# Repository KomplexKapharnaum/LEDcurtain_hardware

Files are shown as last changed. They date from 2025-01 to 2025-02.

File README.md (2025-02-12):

# Teensy KxKm Artnet Node Hardware
**Version: V1.5.0**
# Clément SAILLANT pour KomplexKapharnaüm

Ce projet est la partie hardware d'un nœud Artnet basé sur Teensy 4.1 pour contrôler jusqu'a 50 bandes LED. La Teensy 4.1 est un microcontrôleur puissant capable de piloter un grand nombre de LEDs. Ce projet utilise la bibliothèque FastLED et objectFLED pour contrôler les LEDs et la bibliothèque Artnet pour recevoir les données Artnet.

ce repo contient le Schéma et PCB pour la gestion jusqu'à 40 ruban led en artnet (ou autres) avec une teensy 4.1
avec gestion d'alimentation pour économiser l'énergie quand les ruban de led n'affiche rien.

code disponible ici :
https://github.com/KomplexKapharnaum/LEDcurtain/tree/main

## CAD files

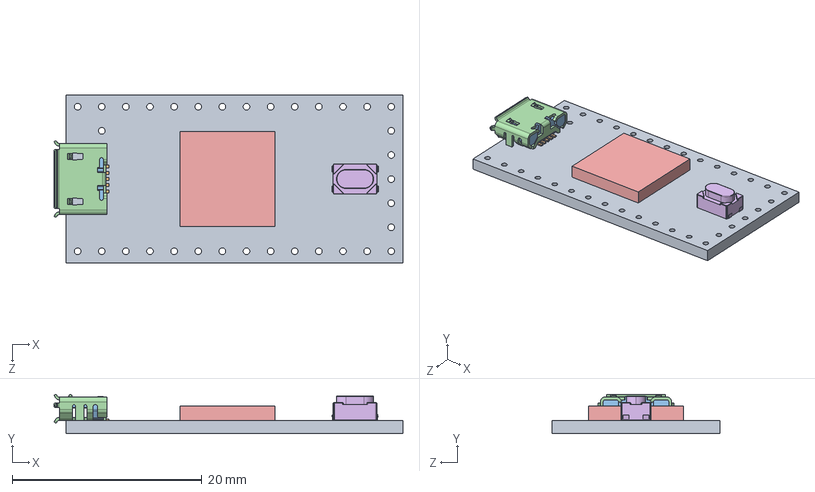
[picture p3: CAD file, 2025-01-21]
Librairie/teensy.pretty-master/Teensy_4.0_Assembly.STEP
36.8 x 4.12 x 17.7 mm
Teensy_4.0_PCB
Micro USB-B Female 5Pin SMD
NXP iMXRT1062
SKRPACE010 v4

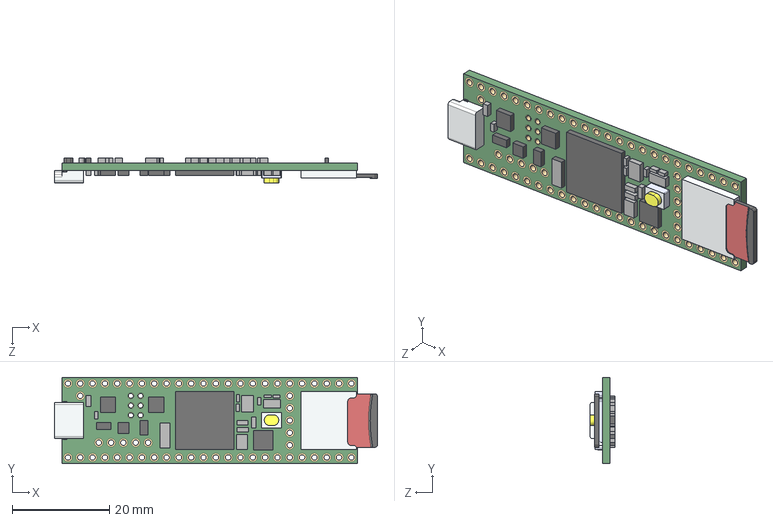
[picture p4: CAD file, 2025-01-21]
casing/Teensy_4.1_Assembly_simplified.STEP
66.6 x 17.8 x 5.06 mm

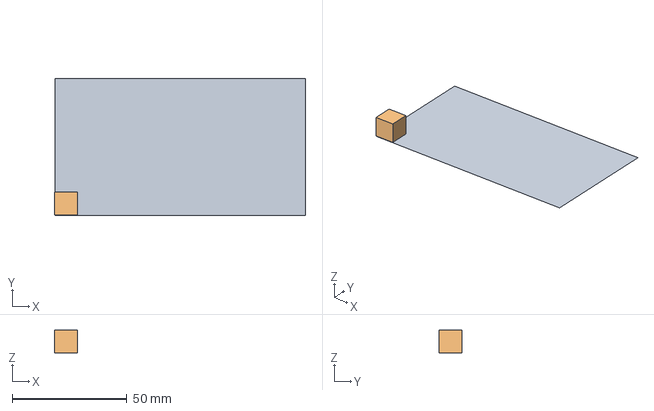
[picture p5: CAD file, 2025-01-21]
casing/LED Board.FCStd
109.6 x 59.8 x 10.0 mm
Rectangle

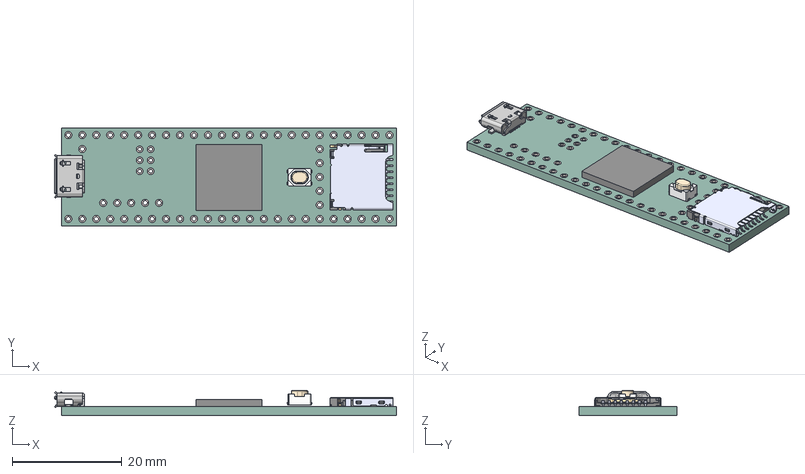
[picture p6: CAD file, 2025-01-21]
casing/teensy-4-1-development-board-1/Teensy 4.1 (Without Headers).step
62.2 x 17.8 x 4.62 mm
114-00841-68--3DModel-STEP-56544
MIMXRT1052CVJ5B
MicroUSB Molex 473460001
PTS810 SJK 250 SMTR LFS

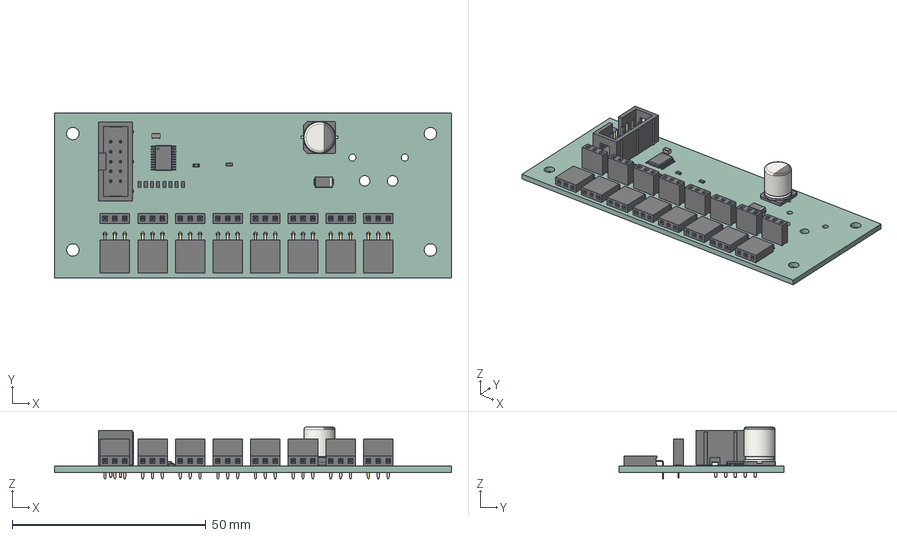
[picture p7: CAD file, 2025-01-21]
LED Board/LED Board.step
102.4 x 42.4 x 13.3 mm
R_0603_1608Metric x 10
PinSocket_1x03_P254mm_Horizontal x 8
PinSocket_1x03_P254mm_Vertical x 8
C_0805_2012Metric
D_SMA
CP_Elec_8x10
IDC_Header_2x05_P254mm_Vertical
TSSOP_20_44x65mm_P065mm
LED Board_PCB

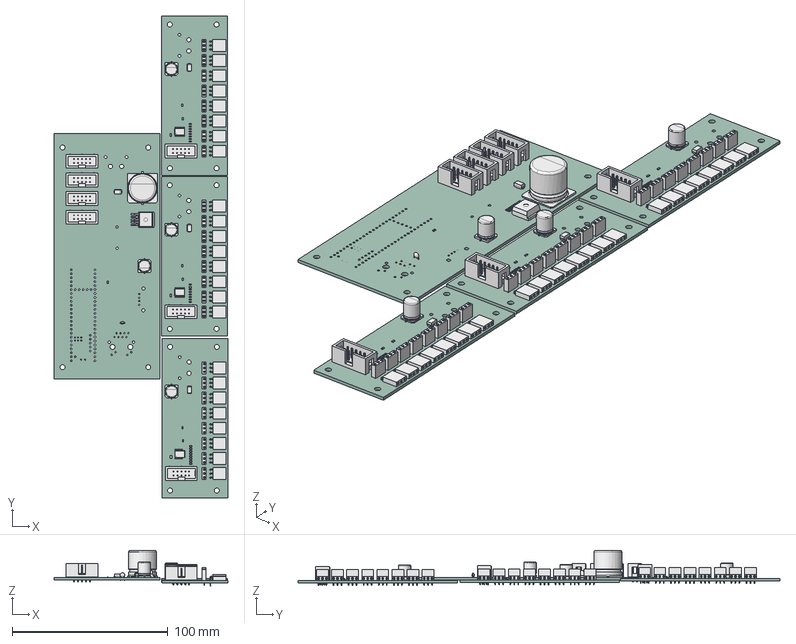
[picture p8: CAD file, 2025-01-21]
casing/Casing all board.FCStd
111.7 x 309.3 x 22.7 mm
CQ assembly
IDC_Header_2x05_P254mm_Vertical
IDC_Header_2x05_P254mm_Vertical001
C_Disc_D30mm_W16mm_P250mm
IDC_Header_2x05_P254mm_Vertical002
CP_Elec_8x10
CP_Elec_18x175
R_0603_1608Metric
D_SMA
IDC_Header_2x05_P254mm_Vertical003
Teensy Board_PCB
R_0603_1608Metric002
PinSocket_1x03_P254mm_Horizontal
PinSocket_1x03_P254mm_Vertical
PinSocket_1x03_P254mm_Vertical001
PinSocket_1x03_P254mm_Horizontal001
PinSocket_1x03_P254mm_Vertical002
PinSocket_1x03_P254mm_Horizontal002
PinSocket_1x03_P254mm_Vertical003
R_0603_1608Metric004
PinSocket_1x03_P254mm_Horizontal003
R_0603_1608Metric006
PinSocket_1x03_P254mm_Vertical004
C_0805_2012Metric
PinSocket_1x03_P254mm_Horizontal004
D_SMA002
R_0603_1608Metric008
R_0603_1608Metric010
R_0603_1608Metric012
R_0603_1608Metric014
PinSocket_1x03_P254mm_Horizontal005
CP_Elec_8x012
PinSocket_1x03_P254mm_Vertical005
PinSocket_1x03_P254mm_Vertical006
R_0603_1608Metric016
PinSocket_1x03_P254mm_Vertical007
PinSocket_1x03_P254mm_Horizontal006
R_0603_1608Metric018
IDC_Header_2x05_P254mm_Vertical004
R_0603_1608Metric020
TSSOP_20_44x65mm_P065mm
PinSocket_1x03_P254mm_Horizontal007
_autosave-LED Board_PCB
R_0603_1608Metric022
PinSocket_1x03_P254mm_Horizontal008
PinSocket_1x03_P254mm_Vertical008
PinSocket_1x03_P254mm_Vertical009
PinSocket_1x03_P254mm_Horizontal009
PinSocket_1x03_P254mm_Vertical010
PinSocket_1x03_P254mm_Horizontal010
PinSocket_1x03_P254mm_Vertical011
R_0603_1608Metric024
PinSocket_1x03_P254mm_Horizontal011
R_0603_1608Metric026
PinSocket_1x03_P254mm_Vertical012
C_0805_2012Metric002
PinSocket_1x03_P254mm_Horizontal012
D_SMA004
R_0603_1608Metric028
R_0603_1608Metric030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

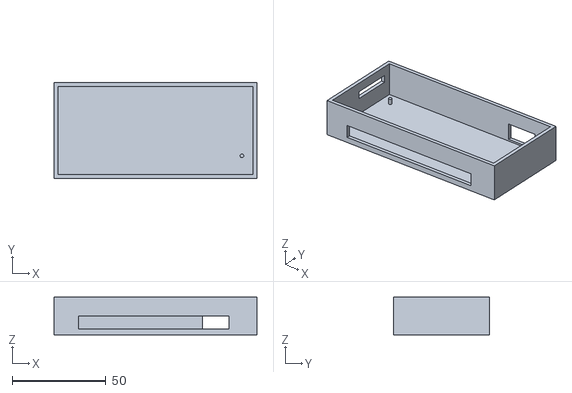
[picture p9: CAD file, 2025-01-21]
casing/led board_thinkercad.stl
108.0 x 51.0 x 20.0

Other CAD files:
casing/LED Board1.FCStd
casing/LED Board-LED Board.stl

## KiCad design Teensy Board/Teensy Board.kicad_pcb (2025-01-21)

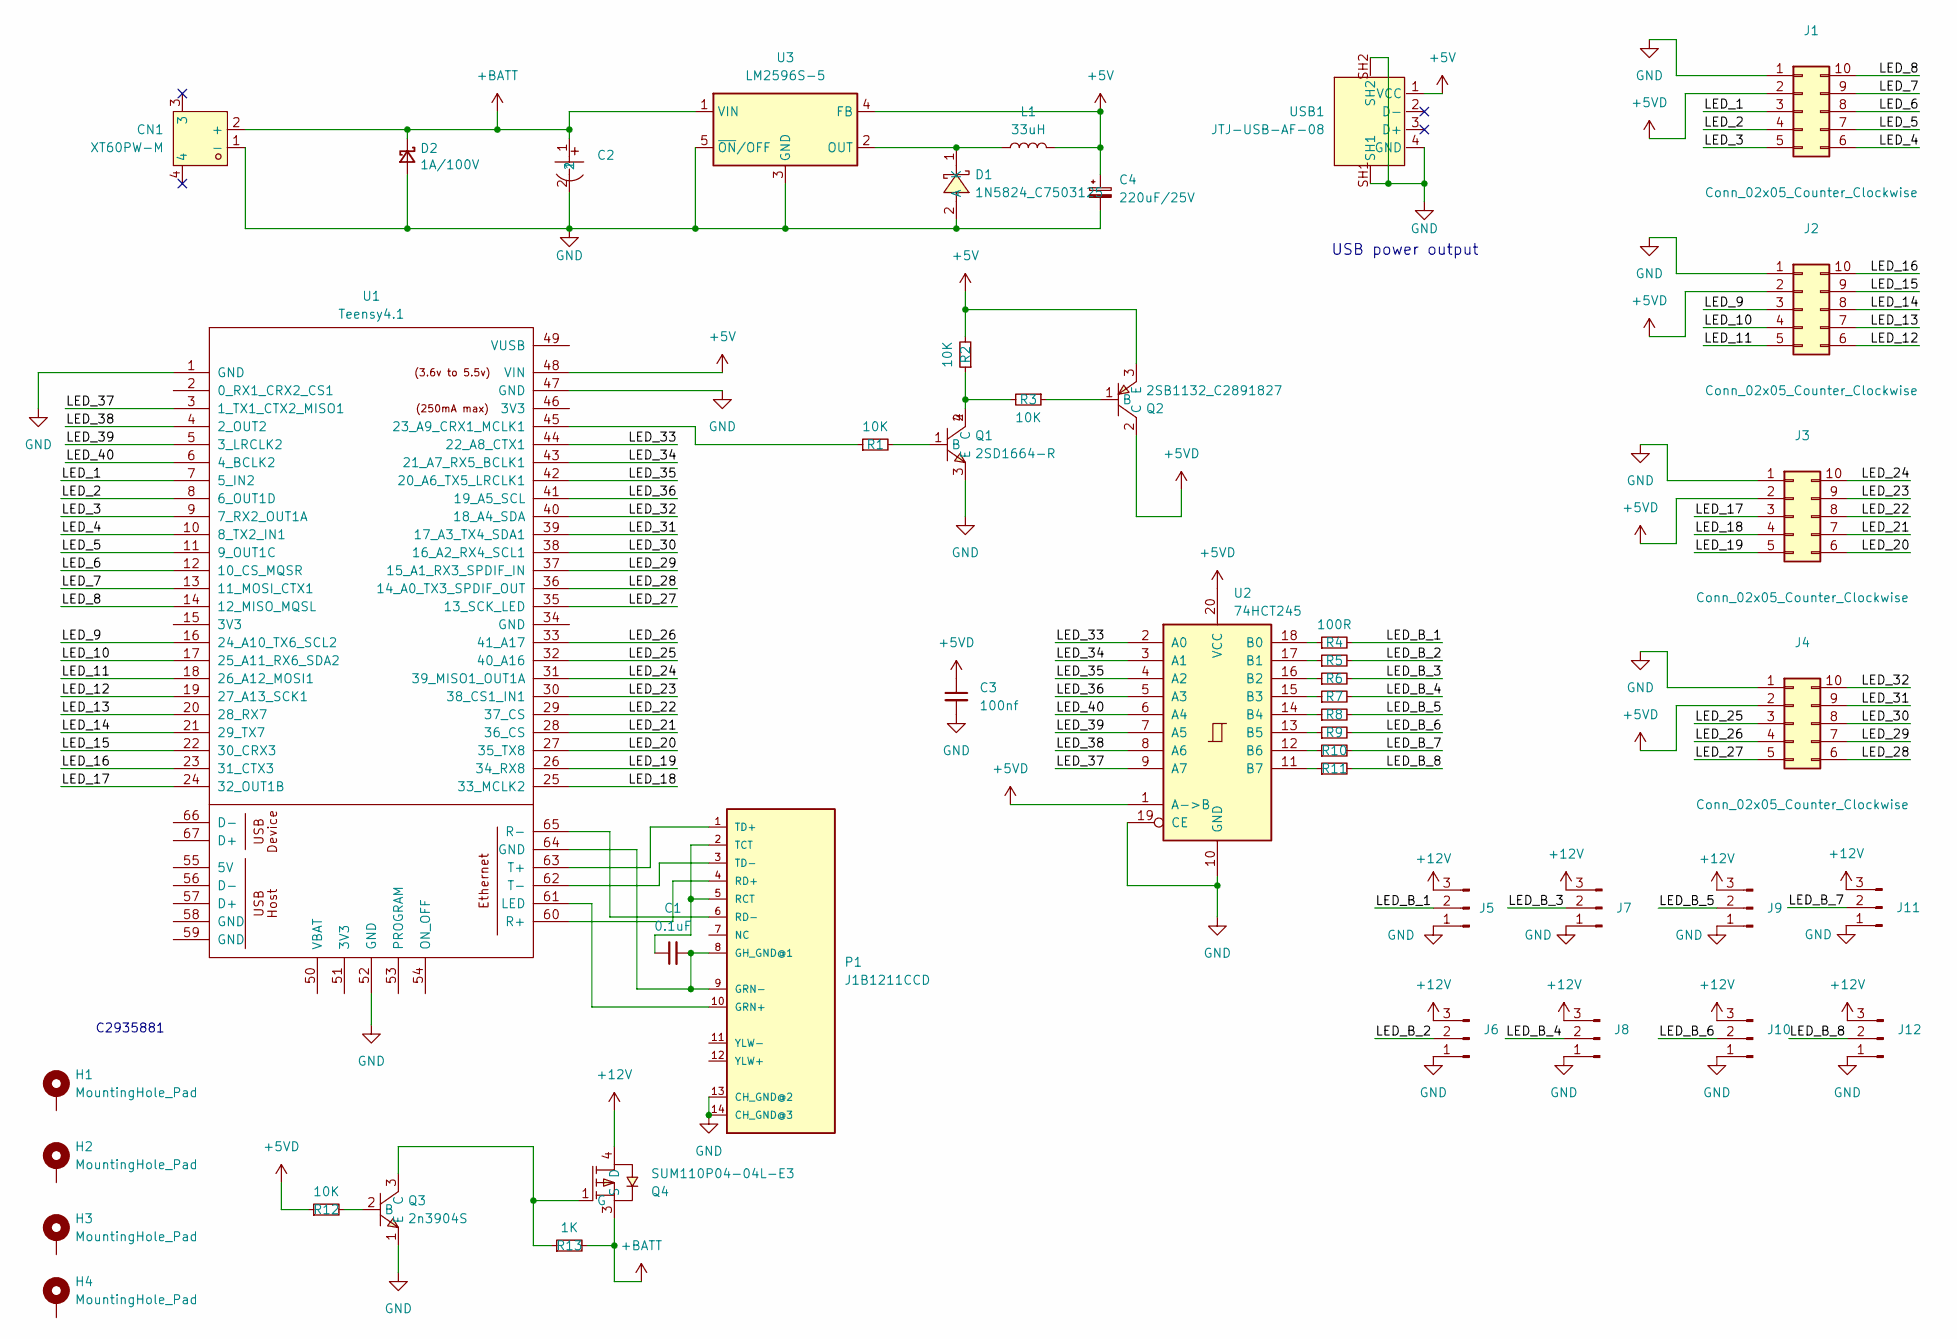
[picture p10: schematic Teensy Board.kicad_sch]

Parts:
C1: 0.1uF; CAP-TH_L3.8-W2.5-P2.50-D0.51; LCSC Part C575458
C2: RVT1H221M1010-C3358; CAP-SMD_BD10.0-L10.3-W10.3-LS11.3-FD; LCSC Part C3358
C3: 100nf; C_0805_2012Metric_Pad1.18x1.45mm_HandSolder; LCSC C14663
C4: 220uF/25V; CP_Elec_8x10; LCSC Part C3353
CN1: XT60PW-M; CONN-TH_XT60PW-M; LCSC Part C98732
D1: 1N5824_C7503125; DO-27_BD5.3-L8.4-P12.40-D1.3-RD; LCSC Part C7503125
D2: 1A/100V; D_SMA; LCSC C14996
H1, H2, H3, H4: MountingHole_Pad; MountingHole_3.2mm_M3_DIN965_Pad_TopOnly
J1, J2, J3, J4: Conn_02x05_Counter_Clockwise; IDC-Header_2x05_P2.54mm_Vertical
J5, J6, J7, J8, J9, J10, J11, J12: Conn_01x03_Pin; PinSocket_1x03_P2.54mm_Vertical
L1: 33uH; L_12x12mm_H6mm
P1: J1B1211CCD; RJ45-TH_J1B1211CCD; LCSC Part C910371
Q1: 2SD1664-R; SOT-89-4_L4.5-W2.5-P1.50-LS4.2-BR; LCSC Part C489328
Q2: 2SB1132_C2891827; SOT-89-3_L4.5-W2.5-P1.50-LS4.0-BR; LCSC Part C2891827
Q3: 2n3904S; SOT-23-3_L2.9-W1.3-P1.90-LS2.4-TR; LCSC Part C18536
Q4: SUM110P04-04L-E3; TO-263-2_L10.1-W9.1-P5.08-LS15.2-TL-1; LCSC Part C222440
R1, R2, R3, R12: 10K; R_0603_1608Metric
R4, R5, R6, R7, R8, R9, R10, R11: 100R; R_0603_1608Metric
R13: 1K; R_0603_1608Metric
U1: Teensy4.1; Teensy41; LCSC Part C2935881
U2: 74HCT245; TSSOP-20_4.4x6.5mm_P0.65mm
U3: LM2596S-5; TO-263-5_TabPin3
USB1: JTJ-USB-AF-08; USB-A-TH__USB-AF-90; LCSC Part C2345

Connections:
+5V: C4.1, L1.2, Q2.3 (E), R2.2, U1.48 (VIN), U3.4 (FB), USB1.1 (VCC)
+5VD: C3.1, J1.2, J2.2, J3.2, J4.2, Q2.2 (C), R12.1, U2.1 (A->B), U2.20 (VCC)
+12V: J5.3, J6.3, J7.3, J8.3, J9.3, J10.3, J11.3, J12.3, Q4.4 (D)
+BATT: C2.1, CN1.2 (+), D2.1 (K), Q4.3 (S), R13.2, U3.1 (VIN)
/LED_1: J1.3, U1.7 (5_IN2)
/LED_2: J1.4, U1.8 (6_OUT1D)
/LED_3: J1.5, U1.9 (7_RX2_OUT1A)
/LED_4: J1.6, U1.10 (8_TX2_IN1)
/LED_5: J1.7, U1.11 (9_OUT1C)
/LED_6: J1.8, U1.12 (10_CS_MQSR)
/LED_7: J1.9, U1.13 (11_MOSI_CTX1)
/LED_8: J1.10, U1.14 (12_MISO_MQSL)
/LED_9: J2.3, U1.16 (24_A10_TX6_SCL2)
/LED_10: J2.4, U1.17 (25_A11_RX6_SDA2)
/LED_11: J2.5, U1.18 (26_A12_MOSI1)
/LED_12: J2.6, U1.19 (27_A13_SCK1)
/LED_13: J2.7, U1.20 (28_RX7)
/LED_14: J2.8, U1.21 (29_TX7)
/LED_15: J2.9, U1.22 (30_CRX3)
/LED_16: J2.10, U1.23 (31_CTX3)
/LED_17: J3.3, U1.24 (32_OUT1B)
/LED_18: J3.4, U1.25 (33_MCLK2)
/LED_19: J3.5, U1.26 (34_RX8)
/LED_20: J3.6, U1.27 (35_TX8)
/LED_21: J3.7, U1.28 (36_CS)
/LED_22: J3.8, U1.29 (37_CS)
/LED_23: J3.9, U1.30 (38_CS1_IN1)
/LED_24: J3.10, U1.31 (39_MISO1_OUT1A)
/LED_25: J4.3, U1.32 (40_A16)
/LED_26: J4.4, U1.33 (41_A17)
/LED_27: J4.5, U1.35 (13_SCK_LED)
/LED_28: J4.6, U1.36 (14_A0_TX3_SPDIF_OUT)
/LED_29: J4.7, U1.37 (15_A1_RX3_SPDIF_IN)
/LED_30: J4.8, U1.38 (16_A2_RX4_SCL1)
/LED_31: J4.9, U1.39 (17_A3_TX4_SDA1)
/LED_32: J4.10, U1.40 (18_A4_SDA)
/LED_33: U1.44 (22_A8_CTX1), U2.2 (A0)
/LED_34: U1.43 (21_A7_RX5_BCLK1), U2.3 (A1)
/LED_35: U1.42 (20_A6_TX5_LRCLK1), U2.4 (A2)
/LED_36: U1.41 (19_A5_SCL), U2.5 (A3)
/LED_37: U1.3 (1_TX1_CTX2_MISO1), U2.9 (A7)
/LED_38: U1.4 (2_OUT2), U2.8 (A6)
/LED_39: U1.5 (3_LRCLK2), U2.7 (A5)
/LED_40: U1.6 (4_BCLK2), U2.6 (A4)
/LED_B_1: J5.2, R4.2
/LED_B_2: J6.2, R5.2
/LED_B_3: J7.2, R6.2
/LED_B_4: J8.2, R7.2
/LED_B_5: J9.2, R8.2
/LED_B_6: J10.2, R9.2
/LED_B_7: J11.2, R10.2
/LED_B_8: J12.2, R11.2
GND: C2.2, C3.2, C4.2, CN1.1 (-), D1.2 (A), D2.2 (A), J1.1, J2.1, J3.1, J4.1, J5.1, J6.1, J7.1, J8.1, J9.1, J10.1, J11.1, J12.1, P1.13 (CH_GND@2), P1.14 (CH_GND@3), Q1.3 (E), Q3.1 (E), U1.1 (GND), U1.47 (GND), U1.52 (GND), U2.10 (GND), U2.19 (CE), U3.3 (GND), U3.5 (~ON/OFF), USB1.4 (GND), USB1.SH1, USB1.SH2
unnamed: D1.1 (K), L1.1, U3.2 (OUT)
unnamed: C1.2, P1.8 (GH_GND@1), P1.9 (GRN-), U1.64 (GND)
unnamed: P1.10 (GRN+), U1.61 (LED)
unnamed: C1.1, P1.2 (TCT), P1.5 (RCT)
unnamed: P1.4 (RD+), U1.60 (R+)
unnamed: P1.6 (RD-), U1.65 (R-)
unnamed: P1.1 (TD+), U1.63 (T+)
unnamed: P1.3 (TD-), U1.62 (T-)
unnamed: Q1.1 (B), R1.2
unnamed: Q1.2 (C), Q1.4 (C), R2.1, R3.2
unnamed: Q2.1 (B), R3.1
unnamed: Q3.2 (B), R12.2
unnamed: Q3.3 (C), Q4.1 (G), R13.1
unnamed: R1.1, U1.45 (23_A9_CRX1_MCLK1)
unnamed: R4.1, U2.18 (B0)
unnamed: R5.1, U2.17 (B1)
unnamed: R6.1, U2.16 (B2)
unnamed: R7.1, U2.15 (B3)
unnamed: R8.1, U2.14 (B4)
unnamed: R9.1, U2.13 (B5)
unnamed: R10.1, U2.12 (B6)
unnamed: R11.1, U2.11 (B7)

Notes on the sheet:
C2935881
USB power output

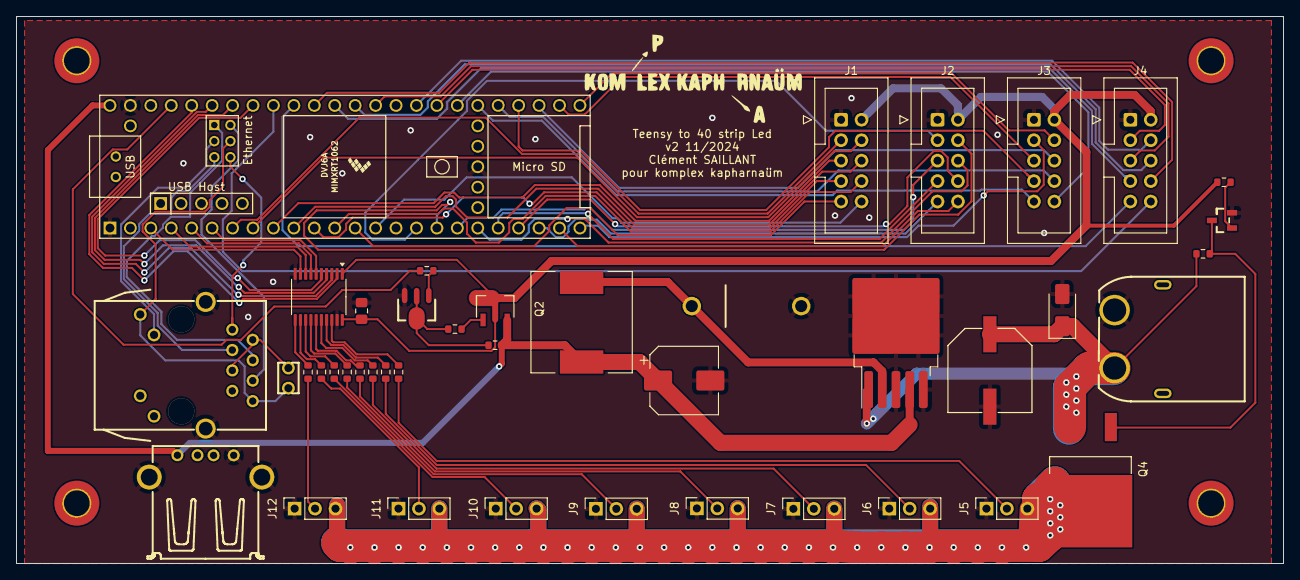
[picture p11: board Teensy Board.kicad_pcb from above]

Board: 2 copper layers, 157.5 x 68.0 mm, 46 parts (0 on the bottom side), 75 nets.

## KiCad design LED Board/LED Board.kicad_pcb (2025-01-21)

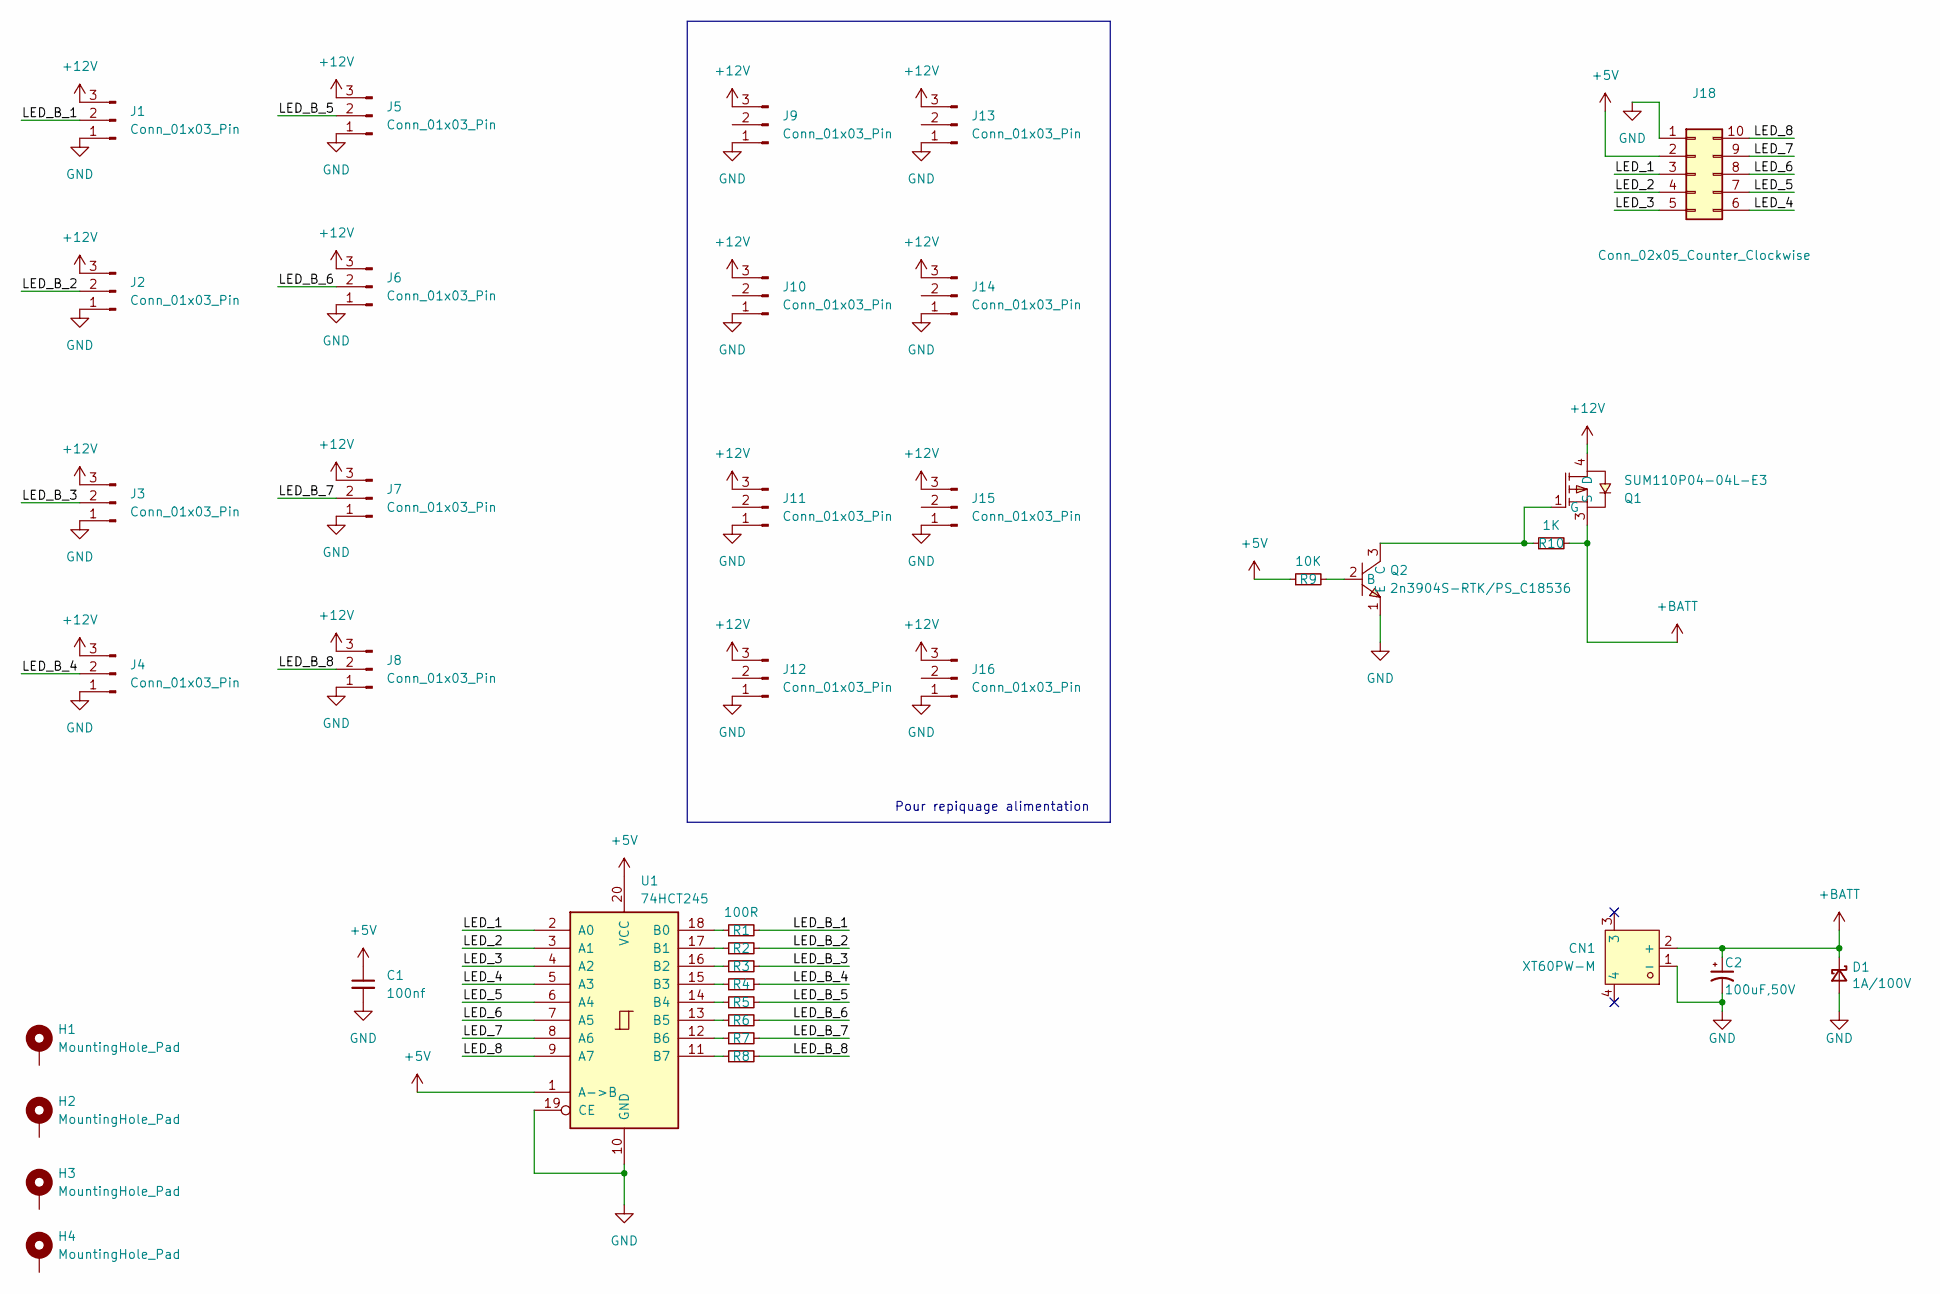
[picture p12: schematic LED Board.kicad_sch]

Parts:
C1: 100nf; C_0805_2012Metric_Pad1.18x1.45mm_HandSolder; LCSC C14663
C2: 100uF,50V; CP_Elec_8x10; LCSC C97812
CN1: XT60PW-M; CONN-TH_XT60PW-M; LCSC Part C98732
D1: 1A/100V; D_SMA; LCSC C14996
H1, H2, H3, H4: MountingHole_Pad; MountingHole_3.2mm_M3_DIN965_Pad_TopOnly
J1, J2, J3, J4, J5, J6, J7, J8: Conn_01x03_Pin; PinSocket_1x03_P2.54mm_Horizontal
J9, J10, J11, J12, J13, J14, J15, J16: Conn_01x03_Pin; PinSocket_1x03_P2.54mm_Vertical
J18: Conn_02x05_Counter_Clockwise; IDC-Header_2x05_P2.54mm_Vertical
Q1: SUM110P04-04L-E3; TO-263-2_L10.1-W9.1-P5.08-LS15.2-TL-1; LCSC Part C222440
Q2: 2n3904S-RTK/PS_C18536; SOT-23-3_L2.9-W1.3-P1.90-LS2.4-TR; LCSC Part C18536
R1, R2, R3, R4, R5, R6, R7, R8: 100R; R_0603_1608Metric
R9: 10K; R_0603_1608Metric
R10: 1K; R_0603_1608Metric
U1: 74HCT245; TSSOP-20_4.4x6.5mm_P0.65mm

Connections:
+5V: C1.1, J18.2, R9.1, U1.1 (A->B), U1.20 (VCC)
+12V: J1.3, J2.3, J3.3, J4.3, J5.3, J6.3, J7.3, J8.3, J9.3, J10.3, J11.3, J12.3, J13.3, J14.3, J15.3, J16.3, Q1.4 (D)
+BATT: C2.1, CN1.2 (+), D1.1 (K), Q1.3 (S), R10.2
/LED_1: J18.3, U1.2 (A0)
/LED_2: J18.4, U1.3 (A1)
/LED_3: J18.5, U1.4 (A2)
/LED_4: J18.6, U1.5 (A3)
/LED_5: J18.7, U1.6 (A4)
/LED_6: J18.8, U1.7 (A5)
/LED_7: J18.9, U1.8 (A6)
/LED_8: J18.10, U1.9 (A7)
/LED_B_1: J1.2, R1.2
/LED_B_2: J2.2, R2.2
/LED_B_3: J3.2, R3.2
/LED_B_4: J4.2, R4.2
/LED_B_5: J5.2, R5.2
/LED_B_6: J6.2, R6.2
/LED_B_7: J7.2, R7.2
/LED_B_8: J8.2, R8.2
GND: C1.2, C2.2, CN1.1 (-), D1.2 (A), J1.1, J2.1, J3.1, J4.1, J5.1, J6.1, J7.1, J8.1, J9.1, J10.1, J11.1, J12.1, J13.1, J14.1, J15.1, J16.1, J18.1, Q2.1 (E), U1.10 (GND), U1.19 (CE)
unnamed: Q1.1 (G), Q2.3 (C), R10.1
unnamed: Q2.2 (B), R9.2
unnamed: R1.1, U1.18 (B0)
unnamed: R2.1, U1.17 (B1)
unnamed: R3.1, U1.16 (B2)
unnamed: R4.1, U1.15 (B3)
unnamed: R5.1, U1.14 (B4)
unnamed: R6.1, U1.13 (B5)
unnamed: R7.1, U1.12 (B6)
unnamed: R8.1, U1.11 (B7)

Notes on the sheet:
Pour repiquage alimentation

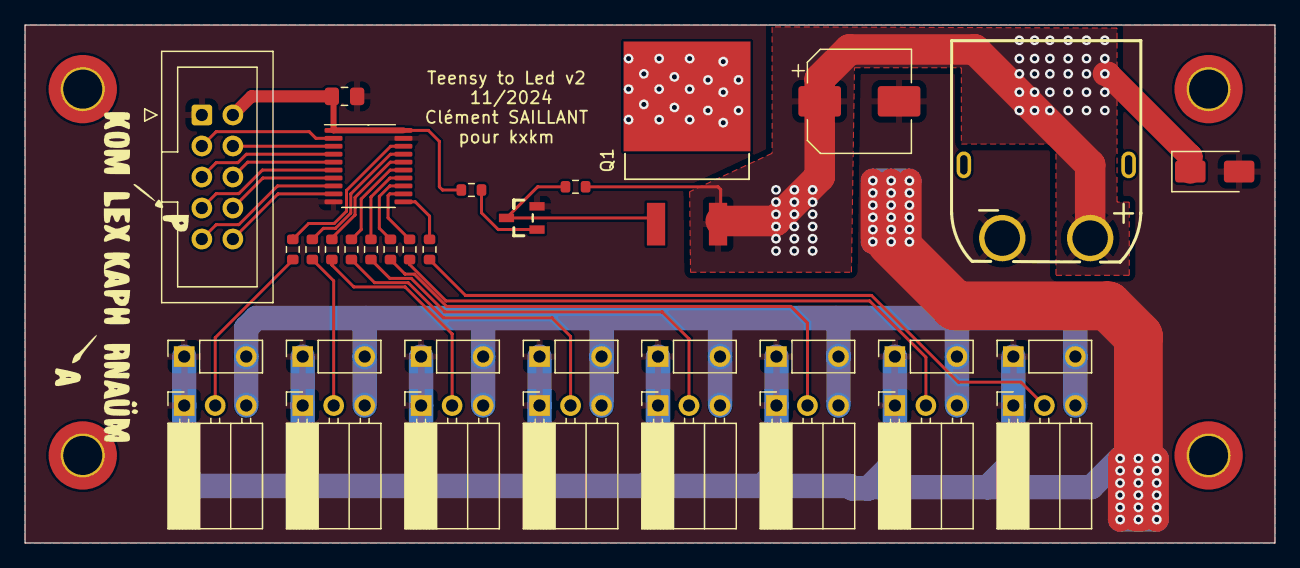
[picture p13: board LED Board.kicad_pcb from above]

Board: 2 copper layers, 102.4 x 42.4 mm, 38 parts (0 on the bottom side), 30 nets.

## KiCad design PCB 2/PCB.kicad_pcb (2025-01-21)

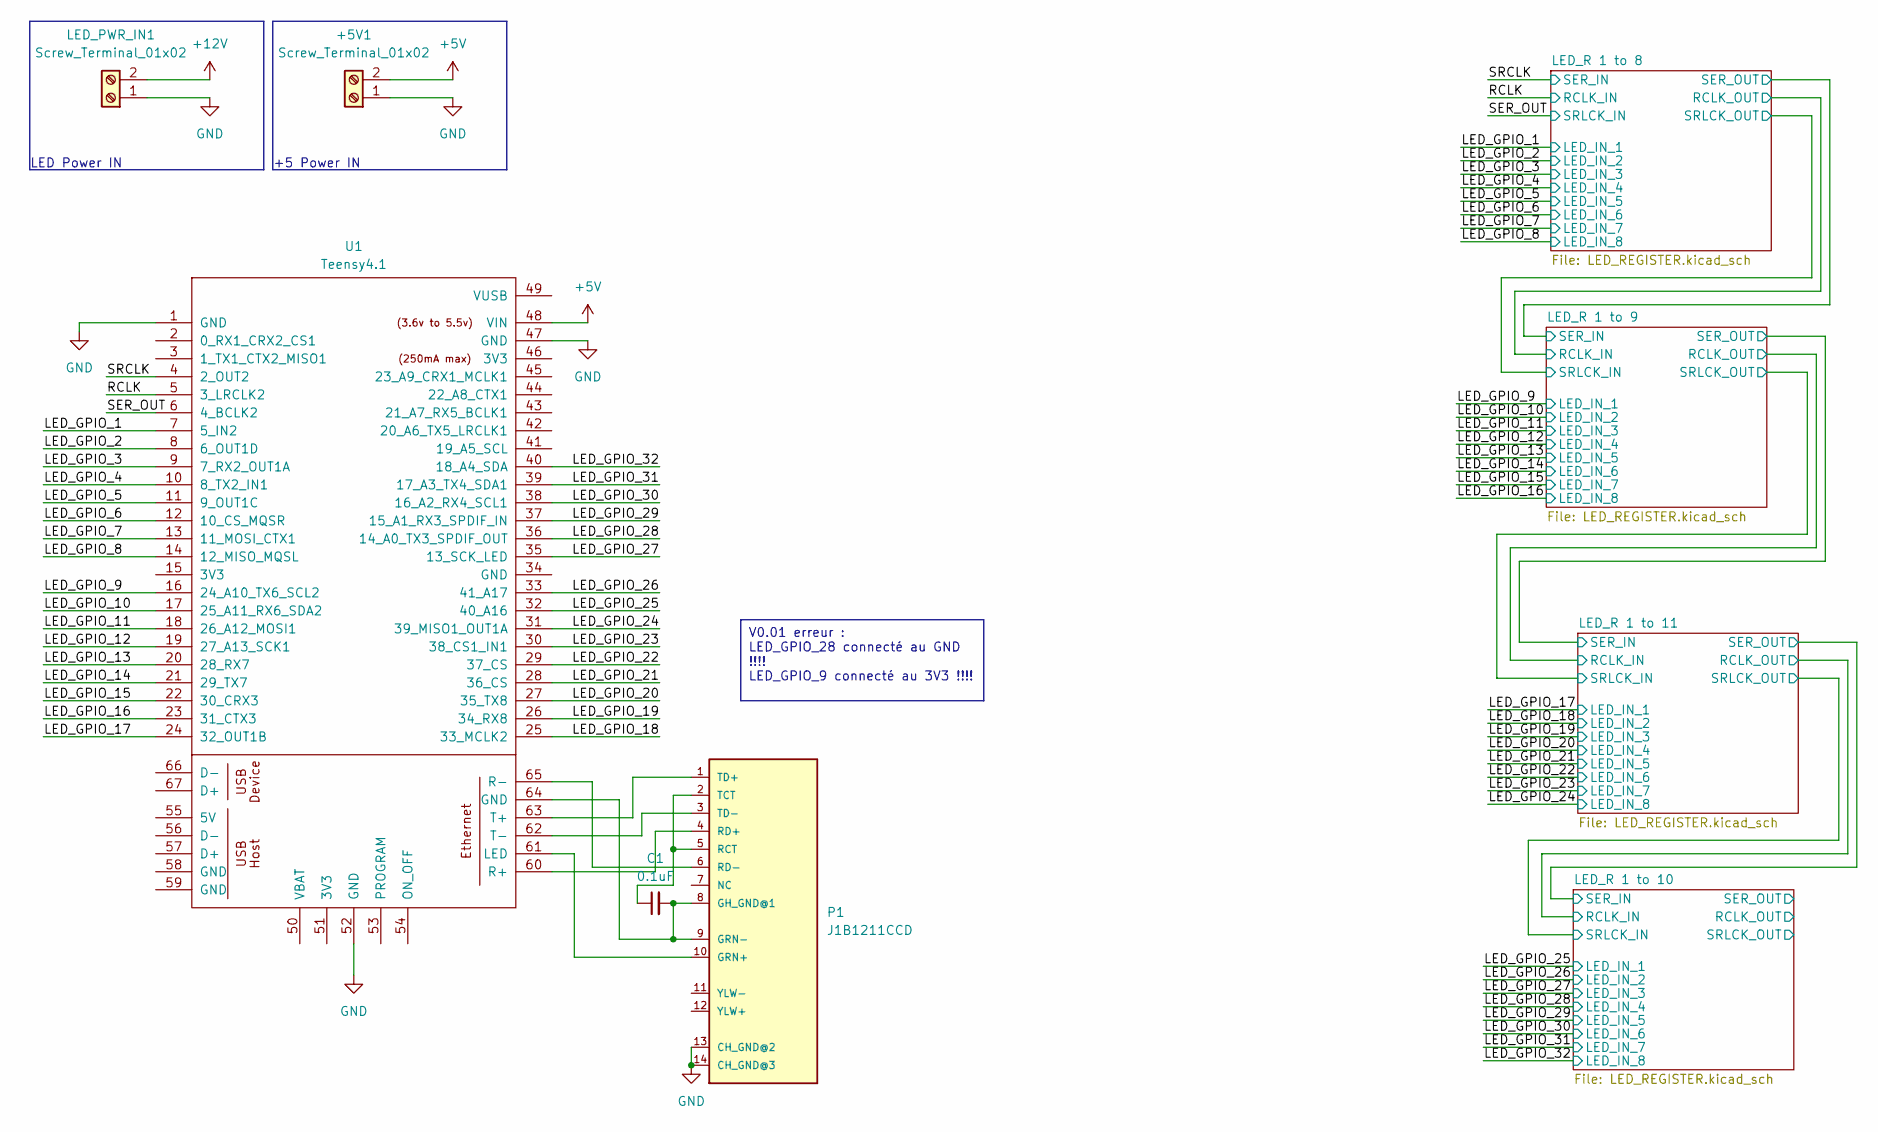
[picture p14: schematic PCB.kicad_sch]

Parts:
+5V1: Screw_Terminal_01x02; Wago_734-162_1x02_P3.50mm_Horizontal
C1: 0.1uF; C_Disc_D3.0mm_W1.6mm_P2.50mm
LED_PWR_IN1: Screw_Terminal_01x02; SolderWire-2.5sqmm_1x02_P8.8mm_D2.4mm_OD4.4mm
P1: J1B1211CCD
U1: Teensy4.1; Teensy41

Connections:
+5V: +5V1.2, U1.48 (VIN); also elsewhere on the board
+12V: LED_PWR_IN1.2; also elsewhere on the board
/LED_GPIO_1: U1.7 (5_IN2); also elsewhere on the board
/LED_GPIO_2: U1.8 (6_OUT1D); also elsewhere on the board
/LED_GPIO_3: U1.9 (7_RX2_OUT1A); also elsewhere on the board
/LED_GPIO_4: U1.10 (8_TX2_IN1); also elsewhere on the board
/LED_GPIO_5: U1.11 (9_OUT1C); also elsewhere on the board
/LED_GPIO_6: U1.12 (10_CS_MQSR); also elsewhere on the board
/LED_GPIO_7: U1.13 (11_MOSI_CTX1); also elsewhere on the board
/LED_GPIO_8: U1.14 (12_MISO_MQSL); also elsewhere on the board
/LED_GPIO_9: U1.15 (3V3); also elsewhere on the board
/LED_GPIO_10: U1.16 (24_A10_TX6_SCL2); also elsewhere on the board
/LED_GPIO_11: U1.17 (25_A11_RX6_SDA2); also elsewhere on the board
/LED_GPIO_12: U1.18 (26_A12_MOSI1); also elsewhere on the board
/LED_GPIO_13: U1.19 (27_A13_SCK1); also elsewhere on the board
/LED_GPIO_14: U1.20 (28_RX7); also elsewhere on the board
/LED_GPIO_15: U1.21 (29_TX7); also elsewhere on the board
/LED_GPIO_16: U1.22 (30_CRX3); also elsewhere on the board
/LED_GPIO_17: U1.23 (31_CTX3); also elsewhere on the board
/LED_GPIO_18: U1.24 (32_OUT1B); also elsewhere on the board
/LED_GPIO_19: U1.25 (33_MCLK2); also elsewhere on the board
/LED_GPIO_20: U1.26 (34_RX8); also elsewhere on the board
/LED_GPIO_21: U1.27 (35_TX8); also elsewhere on the board
/LED_GPIO_22: U1.28 (36_CS); also elsewhere on the board
/LED_GPIO_23: U1.29 (37_CS); also elsewhere on the board
/LED_GPIO_24: U1.30 (38_CS1_IN1); also elsewhere on the board
/LED_GPIO_25: U1.31 (39_MISO1_OUT1A); also elsewhere on the board
/LED_GPIO_26: U1.32 (40_A16); also elsewhere on the board
/LED_GPIO_27: U1.33 (41_A17); also elsewhere on the board
/LED_GPIO_28: U1.34 (GND); also elsewhere on the board
/LED_GPIO_29: U1.36 (14_A0_TX3_SPDIF_OUT); also elsewhere on the board
/LED_GPIO_30: U1.37 (15_A1_RX3_SPDIF_IN); also elsewhere on the board
/LED_GPIO_31: U1.38 (16_A2_RX4_SCL1); also elsewhere on the board
/LED_GPIO_32: U1.39 (17_A3_TX4_SDA1); also elsewhere on the board
/RCLK: U1.5 (3_LRCLK2); also elsewhere on the board
/SER_OUT: U1.6 (4_BCLK2); also elsewhere on the board
/SRCLK: U1.4 (2_OUT2); also elsewhere on the board
GND: +5V1.1, LED_PWR_IN1.1, P1.13 (CH_GND@2), P1.14 (CH_GND@3), U1.1 (GND), U1.47 (GND), U1.52 (GND); also elsewhere on the board
unnamed: C1.2, P1.8 (GH_GND@1), P1.9 (GRN-), U1.64 (GND)
unnamed: P1.10 (GRN+), U1.61 (LED)
unnamed: C1.1, P1.2 (TCT), P1.5 (RCT)
unnamed: P1.4 (RD+), U1.60 (R+)
unnamed: P1.6 (RD-), U1.65 (R-)
unnamed: P1.1 (TD+), U1.63 (T+)
unnamed: P1.3 (TD-), U1.62 (T-)

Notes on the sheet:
V0.01 erreur : LED_GPIO_28 connecté au GND !!!! LED_GPIO_9 connecté au 3V3 !!!!
+5 Power IN
LED Power IN

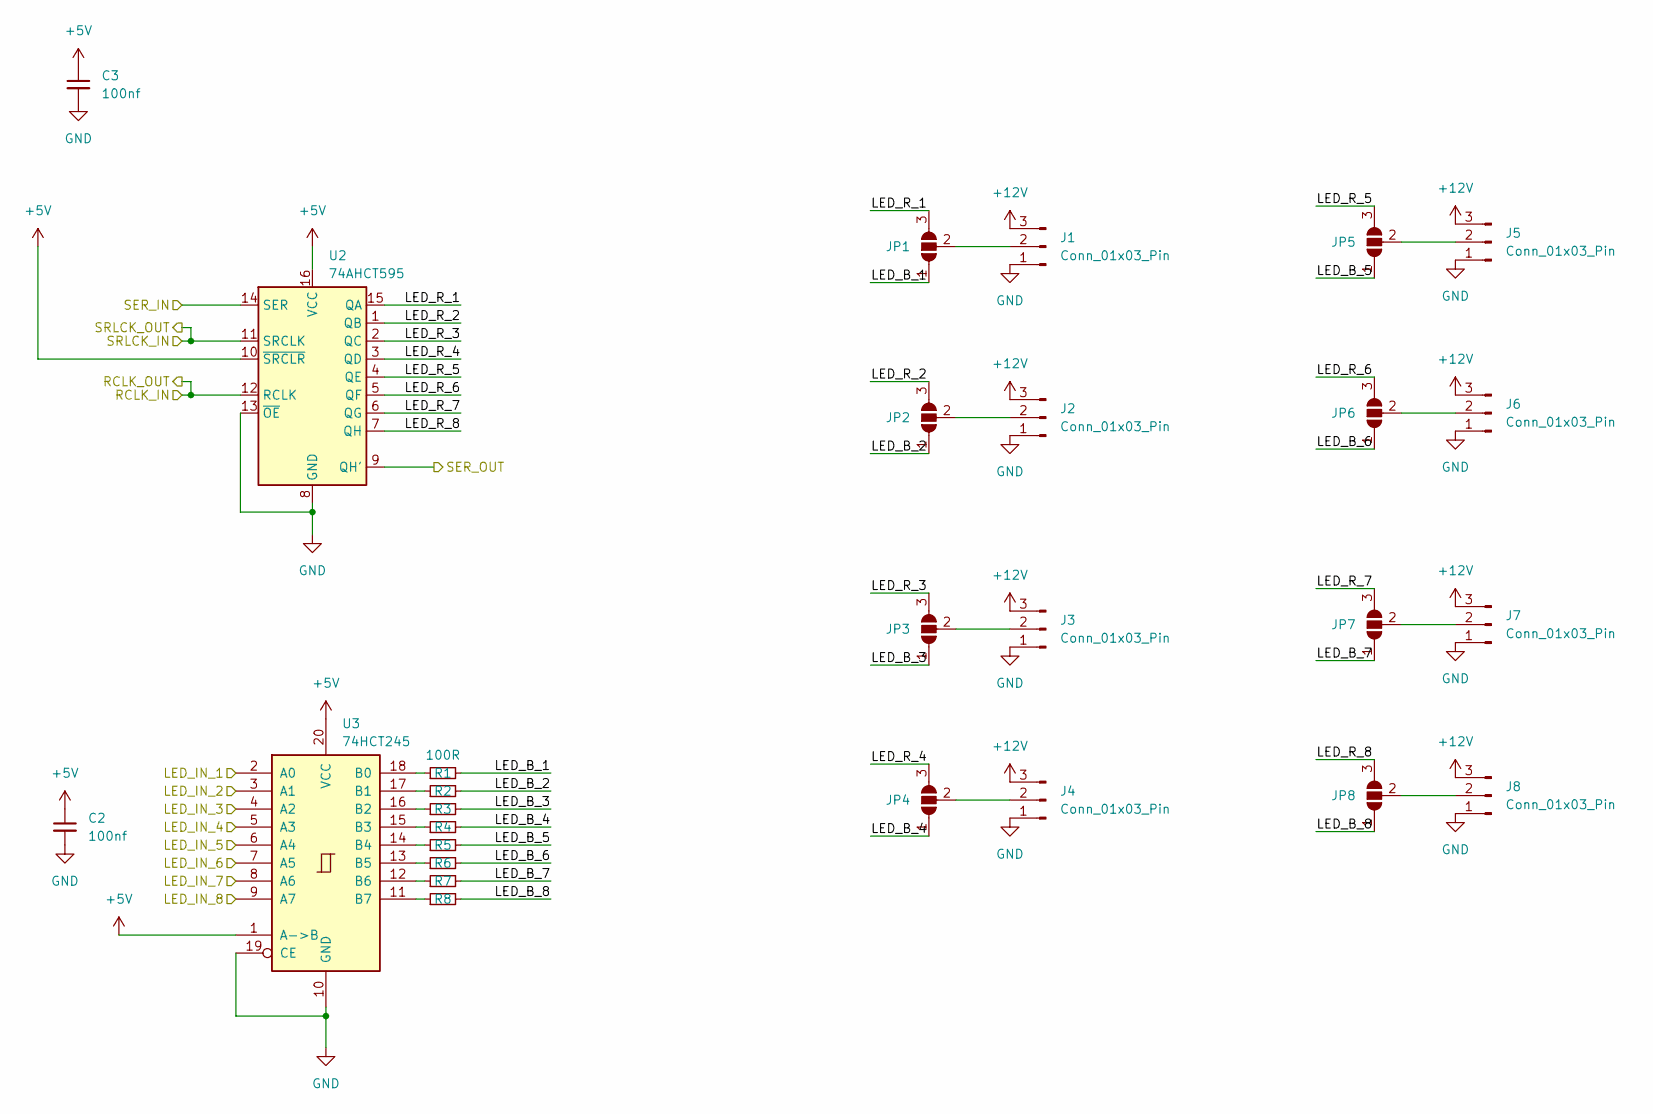
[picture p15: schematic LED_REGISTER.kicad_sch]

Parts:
C2, C3: 100nf; C_0805_2012Metric_Pad1.18x1.45mm_HandSolder; LCSC C14663
J1, J2, J3, J4, J5, J6, J7, J8: Conn_01x03_Pin; SolderWire-2.5sqmm_1x03_P7.2mm_D2.4mm_OD3.6mm
JP1, JP2, JP3, JP4, JP5, JP6, JP7, JP8: SolderJumper_3_Open; SolderJumper-3_P1.3mm_Open_RoundedPad1.0x1.5mm_NumberLabels
R1, R2, R3, R4, R5, R6, R7, R8: 100R; R_0201_0603Metric
U2: 74AHCT595; TSSOP-16_4.4x5mm_P0.65mm
U3: 74HCT245; TSSOP-20_4.4x6.5mm_P0.65mm

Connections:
+5V: C2.1, C3.1, U2.10 (~SRCLR), U2.16 (VCC), U3.1 (A->B), U3.20 (VCC); also elsewhere on the board
+12V: J1.3, J2.3, J3.3, J4.3, J5.3, J6.3, J7.3, J8.3; also elsewhere on the board
/LED_GPIO_1: U3.2 (A0); also elsewhere on the board
/LED_GPIO_2: U3.3 (A1); also elsewhere on the board
/LED_GPIO_3: U3.4 (A2); also elsewhere on the board
/LED_GPIO_4: U3.5 (A3); also elsewhere on the board
/LED_GPIO_5: U3.6 (A4); also elsewhere on the board
/LED_GPIO_6: U3.7 (A5); also elsewhere on the board
/LED_GPIO_7: U3.8 (A6); also elsewhere on the board
/LED_GPIO_8: U3.9 (A7); also elsewhere on the board
/LED_R 1 to 8/LED_B_1: JP1.1 (A), R1.2
/LED_R 1 to 8/LED_B_2: JP2.1 (A), R2.2
/LED_R 1 to 8/LED_B_3: JP3.1 (A), R3.2
/LED_R 1 to 8/LED_B_4: JP4.1 (A), R4.2
/LED_R 1 to 8/LED_B_5: JP5.1 (A), R5.2
/LED_R 1 to 8/LED_B_6: JP6.1 (A), R6.2
/LED_R 1 to 8/LED_B_7: JP7.1 (A), R7.2
/LED_R 1 to 8/LED_B_8: JP8.1 (A), R8.2
/LED_R 1 to 8/LED_R_1: JP1.3 (B), U2.15 (QA)
/LED_R 1 to 8/LED_R_2: JP2.3 (B), U2.1 (QB)
/LED_R 1 to 8/LED_R_3: JP3.3 (B), U2.2 (QC)
/LED_R 1 to 8/LED_R_4: JP4.3 (B), U2.3 (QD)
/LED_R 1 to 8/LED_R_5: JP5.3 (B), U2.4 (QE)
/LED_R 1 to 8/LED_R_6: JP6.3 (B), U2.5 (QF)
/LED_R 1 to 8/LED_R_7: JP7.3 (B), U2.6 (QG)
/LED_R 1 to 8/LED_R_8: JP8.3 (B), U2.7 (QH)
/LED_R 1 to 8/SER_OUT: U2.9 (QH'); also elsewhere on the board
/RCLK: U2.12 (RCLK); also elsewhere on the board
/SER_OUT: U2.11 (SRCLK); also elsewhere on the board
/SRCLK: U2.14 (SER); also elsewhere on the board
GND: C2.2, C3.2, J1.1, J2.1, J3.1, J4.1, J5.1, J6.1, J7.1, J8.1, U2.8 (GND), U2.13 (~OE), U3.10 (GND), U3.19 (CE); also elsewhere on the board
unnamed: J1.2, JP1.2 (C)
unnamed: J2.2, JP2.2 (C)
unnamed: J3.2, JP3.2 (C)
unnamed: J4.2, JP4.2 (C)
unnamed: J5.2, JP5.2 (C)
unnamed: J6.2, JP6.2 (C)
unnamed: J7.2, JP7.2 (C)
unnamed: J8.2, JP8.2 (C)
unnamed: R1.1, U3.18 (B0)
unnamed: R2.1, U3.17 (B1)
unnamed: R3.1, U3.16 (B2)
unnamed: R4.1, U3.15 (B3)
unnamed: R5.1, U3.14 (B4)
unnamed: R6.1, U3.13 (B5)
unnamed: R7.1, U3.12 (B6)
unnamed: R8.1, U3.11 (B7)

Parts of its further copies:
C4, C5, C6, C7, C8, C9: 100nf; C_0805_2012Metric_Pad1.18x1.45mm_HandSolder; LCSC C14663
J9, J10, J11, J12, J13, J14, J15, J16, J17, J18, J19, J20, J21, J22, J23, J24, J25, J26, J27, J28, J29, J30, J31, J32: Conn_01x03_Pin; SolderWire-2.5sqmm_1x03_P7.2mm_D2.4mm_OD3.6mm
JP9, JP10, JP11, JP12, JP13, JP14, JP15, JP16, JP17, JP18, JP19, JP20, JP21, JP22, JP23, JP24, JP25, JP26, JP27, JP28, JP29, JP30, JP31, JP32: SolderJumper_3_Open; SolderJumper-3_P1.3mm_Open_RoundedPad1.0x1.5mm_NumberLabels
R9, R10, R11, R12, R13, R14, R15, R16, R17, R18, R19, R20, R21, R22, R23, R24, R25, R26, R27, R28, R29, R30, R31, R32: 100R; R_0201_0603Metric
U4, U6, U8: 74AHCT595; TSSOP-16_4.4x5mm_P0.65mm
U5, U7, U9: 74HCT245; TSSOP-20_4.4x6.5mm_P0.65mm

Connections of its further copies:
+5V: C4.1, C5.1, C6.1, C7.1, C8.1, C9.1, U4.10 (~SRCLR), U4.16 (VCC), U5.1 (A->B), U5.20 (VCC), U6.10 (~SRCLR), U6.16 (VCC), U7.1 (A->B), U7.20 (VCC), U8.10 (~SRCLR), U8.16 (VCC), U9.1 (A->B), U9.20 (VCC); also elsewhere on the board
+12V: J9.3, J10.3, J11.3, J12.3, J13.3, J14.3, J15.3, J16.3, J17.3, J18.3, J19.3, J20.3, J21.3, J22.3, J23.3, J24.3, J25.3, J26.3, J27.3, J28.3, J29.3, J30.3, J31.3, J32.3; also elsewhere on the board
/LED_GPIO_9: U5.2 (A0); also elsewhere on the board
/LED_GPIO_10: U5.3 (A1); also elsewhere on the board
/LED_GPIO_11: U5.4 (A2); also elsewhere on the board
/LED_GPIO_12: U5.5 (A3); also elsewhere on the board
/LED_GPIO_13: U5.6 (A4); also elsewhere on the board
/LED_GPIO_14: U5.7 (A5); also elsewhere on the board
/LED_GPIO_15: U5.8 (A6); also elsewhere on the board
/LED_GPIO_16: U5.9 (A7); also elsewhere on the board
/LED_GPIO_17: U7.2 (A0); also elsewhere on the board
/LED_GPIO_18: U7.3 (A1); also elsewhere on the board
/LED_GPIO_19: U7.4 (A2); also elsewhere on the board
/LED_GPIO_20: U7.5 (A3); also elsewhere on the board
/LED_GPIO_21: U7.6 (A4); also elsewhere on the board
/LED_GPIO_22: U7.7 (A5); also elsewhere on the board
/LED_GPIO_23: U7.8 (A6); also elsewhere on the board
/LED_GPIO_24: U7.9 (A7); also elsewhere on the board
/LED_GPIO_25: U9.2 (A0); also elsewhere on the board
/LED_GPIO_26: U9.3 (A1); also elsewhere on the board
/LED_GPIO_27: U9.4 (A2); also elsewhere on the board
/LED_GPIO_28: U9.5 (A3); also elsewhere on the board
/LED_GPIO_29: U9.6 (A4); also elsewhere on the board
/LED_GPIO_30: U9.7 (A5); also elsewhere on the board
/LED_GPIO_31: U9.8 (A6); also elsewhere on the board
/LED_GPIO_32: U9.9 (A7); also elsewhere on the board
/LED_R 1 to 8/SER_OUT: U4.14 (SER); also elsewhere on the board
/LED_R 1 to 9/LED_B_1: JP9.1 (A), R9.2
/LED_R 1 to 9/LED_B_2: JP10.1 (A), R10.2
/LED_R 1 to 9/LED_B_3: JP11.1 (A), R11.2
/LED_R 1 to 9/LED_B_4: JP12.1 (A), R12.2
/LED_R 1 to 9/LED_B_5: JP13.1 (A), R13.2
/LED_R 1 to 9/LED_B_6: JP14.1 (A), R14.2
/LED_R 1 to 9/LED_B_7: JP15.1 (A), R15.2
/LED_R 1 to 9/LED_B_8: JP16.1 (A), R16.2
/LED_R 1 to 9/LED_R_1: JP9.3 (B), U4.15 (QA)
/LED_R 1 to 9/LED_R_2: JP10.3 (B), U4.1 (QB)
/LED_R 1 to 9/LED_R_3: JP11.3 (B), U4.2 (QC)
/LED_R 1 to 9/LED_R_4: JP12.3 (B), U4.3 (QD)
/LED_R 1 to 9/LED_R_5: JP13.3 (B), U4.4 (QE)
/LED_R 1 to 9/LED_R_6: JP14.3 (B), U4.5 (QF)
/LED_R 1 to 9/LED_R_7: JP15.3 (B), U4.6 (QG)
/LED_R 1 to 9/LED_R_8: JP16.3 (B), U4.7 (QH)
/LED_R 1 to 10/LED_B_1: JP25.1 (A), R25.2
/LED_R 1 to 10/LED_B_2: JP26.1 (A), R26.2
/LED_R 1 to 10/LED_B_3: JP27.1 (A), R27.2
/LED_R 1 to 10/LED_B_4: JP28.1 (A), R28.2
/LED_R 1 to 10/LED_B_5: JP29.1 (A), R29.2
/LED_R 1 to 10/LED_B_6: JP30.1 (A), R30.2
/LED_R 1 to 10/LED_B_7: JP31.1 (A), R31.2
/LED_R 1 to 10/LED_B_8: JP32.1 (A), R32.2
/LED_R 1 to 10/LED_R_1: JP25.3 (B), U8.15 (QA)
/LED_R 1 to 10/LED_R_2: JP26.3 (B), U8.1 (QB)
/LED_R 1 to 10/LED_R_3: JP27.3 (B), U8.2 (QC)
/LED_R 1 to 10/LED_R_4: JP28.3 (B), U8.3 (QD)
/LED_R 1 to 10/LED_R_5: JP29.3 (B), U8.4 (QE)
/LED_R 1 to 10/LED_R_6: JP30.3 (B), U8.5 (QF)
/LED_R 1 to 10/LED_R_7: JP31.3 (B), U8.6 (QG)
/LED_R 1 to 10/LED_R_8: JP32.3 (B), U8.7 (QH)
/LED_R 1 to 10/SER_IN: U6.9 (QH'), U8.14 (SER)
/LED_R 1 to 10/SER_OUT: U8.9 (QH')
/LED_R 1 to 11/LED_B_1: JP17.1 (A), R17.2
/LED_R 1 to 11/LED_B_2: JP18.1 (A), R18.2
/LED_R 1 to 11/LED_B_3: JP19.1 (A), R19.2
/LED_R 1 to 11/LED_B_4: JP20.1 (A), R20.2
/LED_R 1 to 11/LED_B_5: JP21.1 (A), R21.2
/LED_R 1 to 11/LED_B_6: JP22.1 (A), R22.2
/LED_R 1 to 11/LED_B_7: JP23.1 (A), R23.2
/LED_R 1 to 11/LED_B_8: JP24.1 (A), R24.2
/LED_R 1 to 11/LED_R_1: JP17.3 (B), U6.15 (QA)
/LED_R 1 to 11/LED_R_2: JP18.3 (B), U6.1 (QB)
/LED_R 1 to 11/LED_R_3: JP19.3 (B), U6.2 (QC)
/LED_R 1 to 11/LED_R_4: JP20.3 (B), U6.3 (QD)
/LED_R 1 to 11/LED_R_5: JP21.3 (B), U6.4 (QE)
/LED_R 1 to 11/LED_R_6: JP22.3 (B), U6.5 (QF)
/LED_R 1 to 11/LED_R_7: JP23.3 (B), U6.6 (QG)
/LED_R 1 to 11/LED_R_8: JP24.3 (B), U6.7 (QH)
/LED_R 1 to 11/SER_IN: U4.9 (QH'), U6.14 (SER)
/RCLK: U4.12 (RCLK), U6.12 (RCLK), U8.12 (RCLK); also elsewhere on the board
/SER_OUT: U4.11 (SRCLK), U6.11 (SRCLK), U8.11 (SRCLK); also elsewhere on the board
GND: C4.2, C5.2, C6.2, C7.2, C8.2, C9.2, J9.1, J10.1, J11.1, J12.1, J13.1, J14.1, J15.1, J16.1, J17.1, J18.1, J19.1, J20.1, J21.1, J22.1, J23.1, J24.1, J25.1, J26.1, J27.1, J28.1, J29.1, J30.1, J31.1, J32.1, U4.8 (GND), U4.13 (~OE), U5.10 (GND), U5.19 (CE), U6.8 (GND), U6.13 (~OE), U7.10 (GND), U7.19 (CE), U8.8 (GND), U8.13 (~OE), U9.10 (GND), U9.19 (CE); also elsewhere on the board
unnamed: J9.2, JP9.2 (C)
unnamed: J10.2, JP10.2 (C)
unnamed: J11.2, JP11.2 (C)
unnamed: J12.2, JP12.2 (C)
unnamed: J13.2, JP13.2 (C)
unnamed: J14.2, JP14.2 (C)
unnamed: J15.2, JP15.2 (C)
unnamed: J16.2, JP16.2 (C)
unnamed: J17.2, JP17.2 (C)
unnamed: J18.2, JP18.2 (C)
unnamed: J19.2, JP19.2 (C)
unnamed: J20.2, JP20.2 (C)
unnamed: J21.2, JP21.2 (C)
unnamed: J22.2, JP22.2 (C)
unnamed: J23.2, JP23.2 (C)
unnamed: J24.2, JP24.2 (C)
unnamed: J25.2, JP25.2 (C)
unnamed: J26.2, JP26.2 (C)
unnamed: J27.2, JP27.2 (C)
unnamed: J28.2, JP28.2 (C)
unnamed: J29.2, JP29.2 (C)
unnamed: J30.2, JP30.2 (C)
unnamed: J31.2, JP31.2 (C)
unnamed: J32.2, JP32.2 (C)
unnamed: R9.1, U5.18 (B0)
unnamed: R10.1, U5.17 (B1)
unnamed: R11.1, U5.16 (B2)
unnamed: R12.1, U5.15 (B3)
unnamed: R13.1, U5.14 (B4)
unnamed: R14.1, U5.13 (B5)
unnamed: R15.1, U5.12 (B6)
unnamed: R16.1, U5.11 (B7)
unnamed: R17.1, U7.18 (B0)
unnamed: R18.1, U7.17 (B1)
unnamed: R19.1, U7.16 (B2)
unnamed: R20.1, U7.15 (B3)
unnamed: R21.1, U7.14 (B4)
unnamed: R22.1, U7.13 (B5)
unnamed: R23.1, U7.12 (B6)
unnamed: R24.1, U7.11 (B7)
unnamed: R25.1, U9.18 (B0)
unnamed: R26.1, U9.17 (B1)
unnamed: R27.1, U9.16 (B2)
unnamed: R28.1, U9.15 (B3)
unnamed: R29.1, U9.14 (B4)
unnamed: R30.1, U9.13 (B5)
unnamed: R31.1, U9.12 (B6)
unnamed: R32.1, U9.11 (B7)

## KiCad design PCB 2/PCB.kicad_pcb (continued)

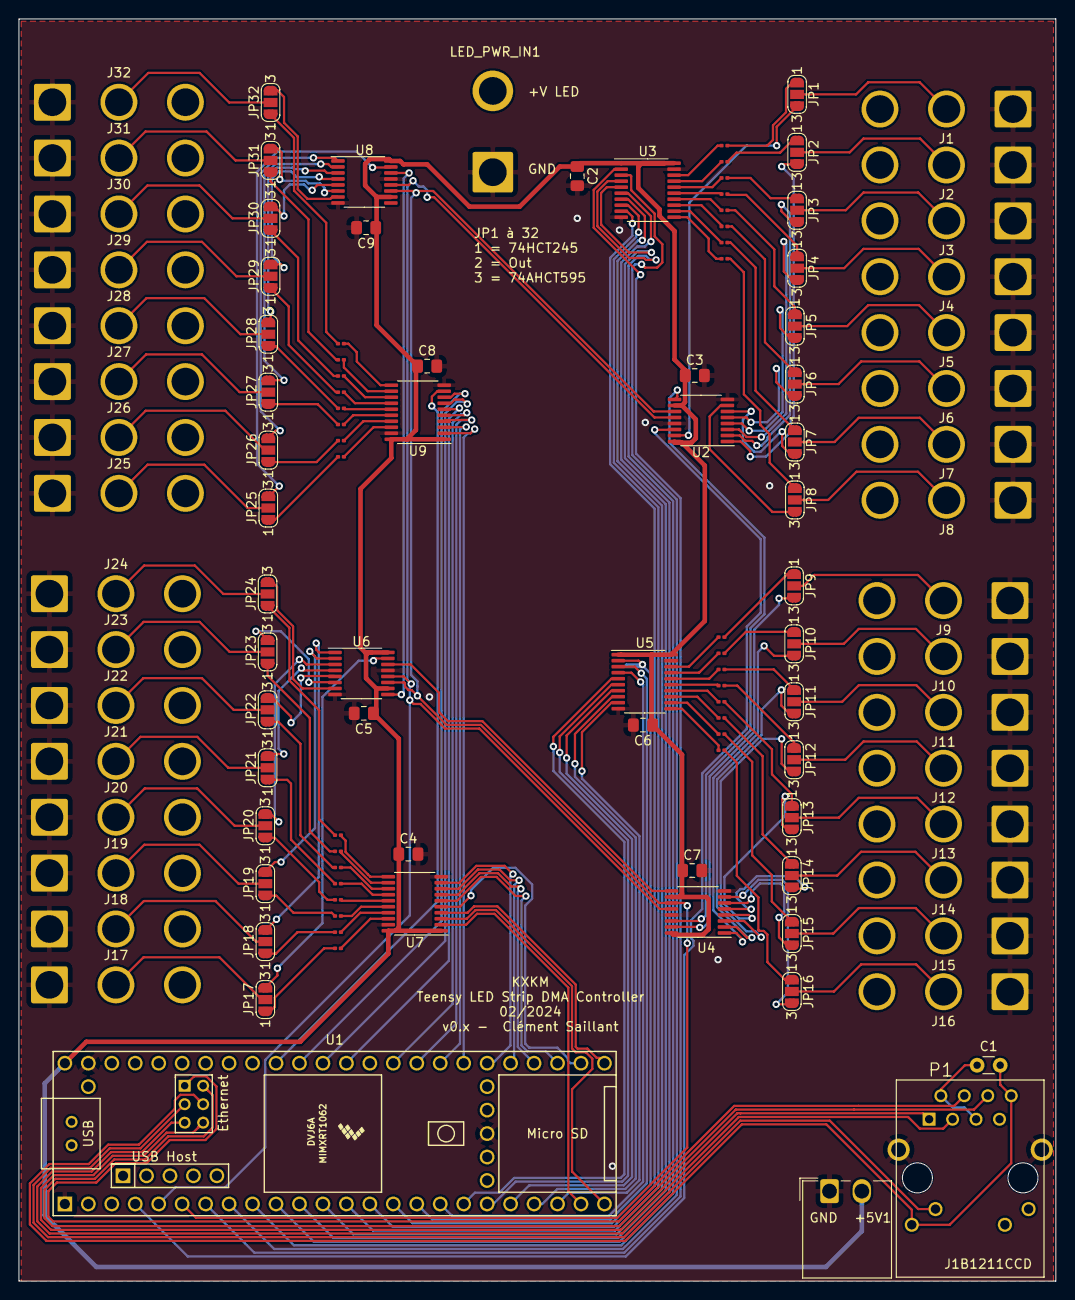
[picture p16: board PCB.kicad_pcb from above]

Board: 2 copper layers, 112.3 x 136.7 mm, 117 parts (0 on the bottom side), 176 nets.

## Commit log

2025-01-21 update pcb v2 abd step file
2025-02-10 update PCB
